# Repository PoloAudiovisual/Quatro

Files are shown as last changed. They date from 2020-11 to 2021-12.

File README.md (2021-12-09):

Front panel, gerbers, BOM and schematics for **[Quatro](https://www.olivellamodular.com/quatro.html), an Eurorack synthesizer module from [Olivella Modular](https://www.olivellamodular.com/)**.

Based on Veils v1 from Mutable Instruments. [Original design](https://github.com/pichenettes/eurorack) by Émilie Gillet. Through-hole remix by Kevin Olivella.

License
=======

[CC BY-SA 3.0][cc-by-sa].

[][cc-by-sa]

[cc-by-sa]: http://creativecommons.org/licenses/by-sa/3.0/
[cc-by-sa-image]: https://licensebuttons.net/l/by-sa/3.0/88x31.png
[cc-by-sa-shield]: https://img.shields.io/badge/License-CC%20BY--SA%203.0-lightgrey.svg

CC BY-SA 3.0 does not confer the right to use intellectual property such as trademarks, brand names, and logos. Olivella Modular, Quatro, Mutable Instruments, and Veils are trademarks of their respective owners and should not be used without permission.

By Kevin Olivella (kev.olivella@gmail.com)

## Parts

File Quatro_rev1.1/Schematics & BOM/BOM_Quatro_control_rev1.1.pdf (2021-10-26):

## BOM Quatro – Control Board – rev 1.1

ID | Name / Value | Designator | Format | QTY
| | Resistors
1 | 510 | R2,R10,R15,R16,R17,R18,R19,R20 | Horizontal | 8
2 | 75k | R3,R6,R9,R13 | Horizontal | 4
3 | 100k | R1,R4,R5,R7,R8,R11,R12,R14 | Horizontal | 8
| | LEDs
4 | 5ARG4HWC 5mm | LED1,LED2,LED3,LED4 | Bipolar LED 5mm | 4
| | Potentiometers
5 | GAIN_1 100kB | P2 | Alpha 9mm – 6.35mm round shaft LONG | 1
6 | GAIN_2 100kB | P4 | Alpha 9mm – 6.35mm round shaft LONG | 1
7 | GAIN_3 100kB | P6 | Alpha 9mm – 6.35mm round shaft LONG | 1
8 | GAIN_4 100kB | P8 | Alpha 9mm – 6.35mm round shaft LONG | 1
9 | CV_1 100kB | P1 | SongHuei 9mm - TALL trimmer | 1
10 | CV_2 100kB | P3 | SongHuei 9mm - TALL trimmer | 1
11 | CV_3 100kB | P5 | SongHuei 9mm - TALL trimmer | 1
12 | CV_4 100kB | P7 | SongHuei 9mm - TALL trimmer | 1
13 | LINEXP_1 100kB | R33 | SongHuei 9mm - TALL trimmer | 1
14 | LINEXP_2 100kB | R34 | SongHuei 9mm - TALL trimmer | 1
15 | LINEXP_3 100kB | R36 | SongHuei 9mm - TALL trimmer | 1
16 | LINEXP_4 100kB | R35 | SongHuei 9mm - TALL trimmer | 1
| | Female headers
17 | VCA_1_2-VCA_3_4 | H1,H2 | HDR-12X1 / 2.54mm | 2
18 | LEDS | H3 | HDR-8X1 / 2.54mm | 1
19 | RAILS | H4 | HDR-5X1 / 2.54mm | 1
| | Jacks
20 | JACKS | J1 to J12 | PJ-3410 | 12
| | Knobs
21 | Rogan RB small – Blue | https://www.thonk.co.uk/shop/rogan-bFor 6.35mm round shaft pots | 4
22 | Hex key – Small | https://www.thonk.co.uk/shop/rogan-bSmall | 1
| | PCB
23 | Control Board | Quatro_control_rev1.1.zip | 58 x 110mm | 1
| | Front panel
23 | Aluminium panel | Quatro.fpd | Anodized, 60.6 x 128.5mm | 1
28 | Panel screws | --- | M3 x 6mm | 4

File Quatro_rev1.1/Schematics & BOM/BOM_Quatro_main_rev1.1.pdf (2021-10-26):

## BOM Quatro - Main Board – rev 1.1

ID | Name / Value | Designator | Format | QTY
| | Resistors
1 | 510 | R1,R4,R23,R26,R36,R39,R49,R52 | Horizontal | 8
2 | 1.2k | R14,R20,R27,R30 | Horizontal | 4
3 | 4.7k | R57,R58,R61,R63 | Horizontal | 4
4 | 5.1k | R8,R9,R11,R16,R18,R19,R29,R31,R32,R44,R45,R53,R54,R55 | Horizontal | 14
5 | 5.6k | R12,R15,R28 | Horizontal | 3
6 | 10k | R41,R42 | Horizontal | 2
7 | 100k | R3,R6,R21,R24,R34,R37,R47,R50 | Horizontal | 8
8 | 1M | R2,R5,R7,R10,R13,R17,R22,R25 | Horizontal | 8
9 | 10M | R56,R59,R60,R62 | Horizontal | 4
| | Diodes
10 | 1N4733 or 1N5231A | D5,D6 | DO-35 | 2
11 | 1N5819 | D1,D2,D3,D4 | DO-41 | 4
| | Ferrite beads
12 | 2743001111 (Mouser) | L1,L2 | AXIAL-L-4.7X3.5 | 2
| | DIP sockets
13 | 14pin | U3,U4,U5,U6,U7 | DIP-14 | 5
14 | 16pin | U1,U2 | DIP-16 | 2
| | Capacitors
15 | 100pF | C1,C4,C5,C6,C7,C10,C11,C12,C15,C16,C17,C20 | CAP-5.08MM | 12
16 | 560pF | C2,C3,C8,C9,C13,C14,C18,C19 | CAP-5.08MM | 8
17 | 100nF | C23,C24,C25,C26,C27,C28,C29,C30,C31,C32,C33,C34,C35,C36 | CAP-5.08MM | 14
18 | 22uF Panasonic | C21,C22 | CAP-D6.3XF2.5 | 2
| | ICs
19 | AS2164 | U1,U2 | DIP-16 | 2
20 | TL074 | U3,U4,U5,U6,U7 | DIP-14 | 5
| | Male headers
21 | VCA_1_2-VCA_3_4 | H1,H2 | HDR-12X1 / 2.54mm | 4
22 | LEDS | H3 | HDR-8X1 / 2.54mm | 1
23 | RAILS | H4 | HDR-5X1 / 2.54mm | 1
24 | POWER | JP1 | 2X5 pin BOX HEADER | 1
| | PCB
25 | Main Board | Quatro_main_rev1.1.zip | 58 x 110mm | 1
| | Hardware
26 | Standoff (Mouser or Thonk) | 710-970110321 (Mouser) | M3 x 11mm (SW5.5) | 2
27 | Standoff screw | --- | M3 x 4mm | 4

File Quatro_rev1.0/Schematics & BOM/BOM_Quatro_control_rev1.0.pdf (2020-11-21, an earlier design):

## BOM Quatro – Control Board – rev. 1.0

ID | Nombre / Valor | Designación | Formato | Cant.
| | Resistencias
1 | 510 | R2,R10,R15,R16,R17,R18,R19,R20 | Horizontal | 8
2 | 75k | R3,R6,R9,R13 | Horizontal | 4
3 | 100k | R1,R4,R5,R7,R8,R11,R12,R14 | Horizontal | 8
| | LEDs
4 | 5ARG4HWC 5mm | LED1,LED2,LED3,LED4 | LED-DIP/5mm | 4
| | Potenciómetros
5 | GAIN_1 100kB | P2 | Alpha 9mm | 1
6 | GAIN_2 100kB | P4 | Alpha 9mm | 1
7 | GAIN_3 100kB | P6 | Alpha 9mm | 1
8 | GAIN_4 100kB | P8 | Alpha 9mm | 1
9 | CV_1 100kB | P1 | SongHuei 9mm trimpot | 1
10 | CV_2 100kB | P3 | SongHuei 9mm trimpot | 1
11 | CV_3 100kB | P5 | SongHuei 9mm trimpot | 1
12 | CV_4 100kB | P7 | SongHuei 9mm trimpot | 1
13 | LINEXP_1 100kB | R33 | SongHuei 9mm trimpot | 1
14 | LINEXP_2 100kB | R34 | SongHuei 9mm trimpot | 1
15 | LINEXP_3 100kB | R36 | SongHuei 9mm trimpot | 1
16 | LINEXP_4 100kB | R35 | SongHuei 9mm trimpot | 1
| | Jacks
20 | JACKS | J1 a J12 | PJ-3410, JAPAN | 12
| | Conectores (hembra)
17 | VCA | P9,P10,P11,P12 | HDR-6X1/2.54mm | 4
18 | RAILS | P13 | HDR-5X1/2.54mm | 1
19 | LEDS | P14 | HDR-8X1/2.54mm | 1

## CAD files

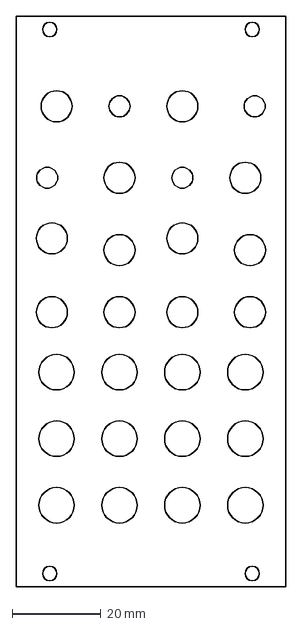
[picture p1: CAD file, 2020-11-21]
Front panel/Quatro_CNC.dxf
60.6 x 128.5 mm

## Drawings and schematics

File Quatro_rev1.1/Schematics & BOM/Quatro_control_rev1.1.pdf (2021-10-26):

# Audio in Audio out

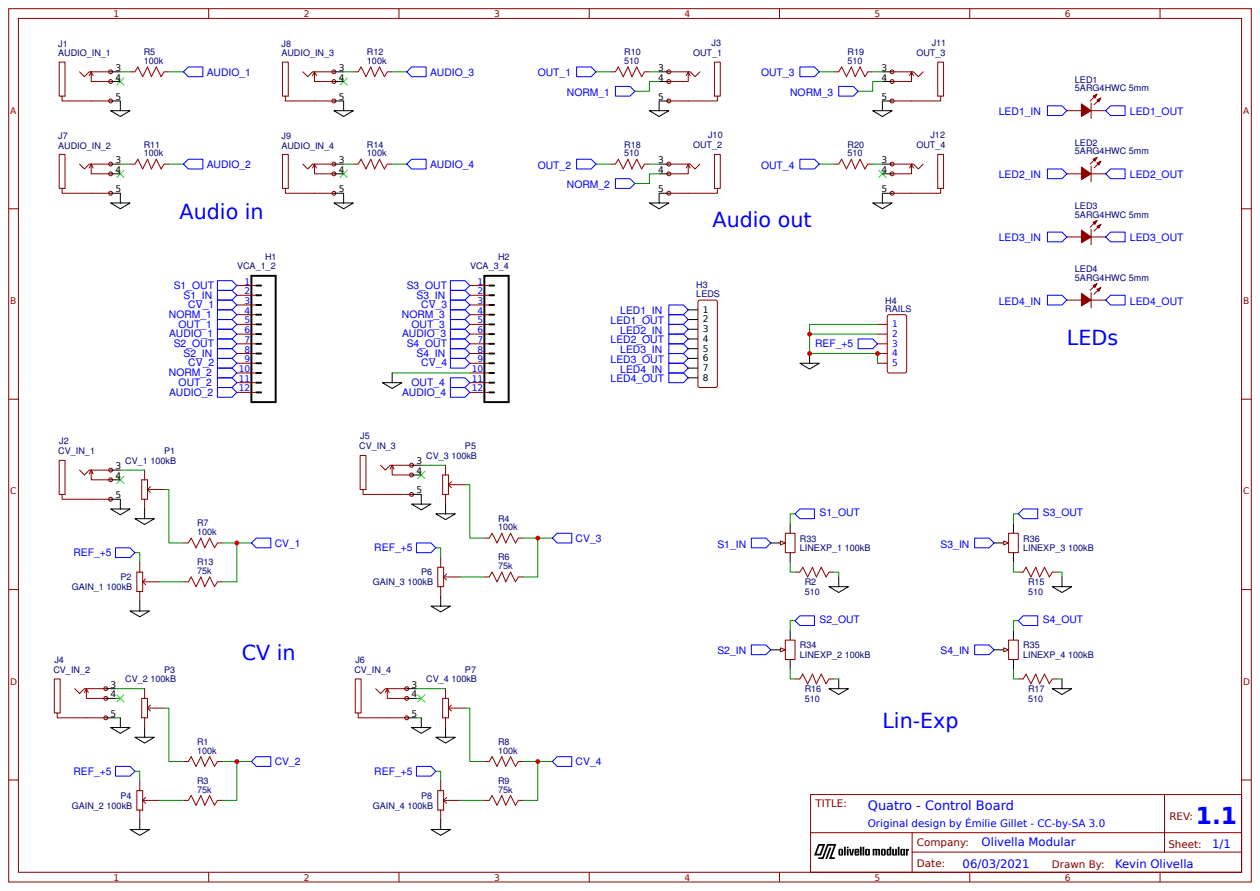
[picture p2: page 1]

Original design by Émilie Gillet - CC-by-SA 3.0

Drawn By: Kevin Olivella

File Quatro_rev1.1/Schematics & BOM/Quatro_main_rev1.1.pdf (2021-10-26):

VCA 1 | VCA 2

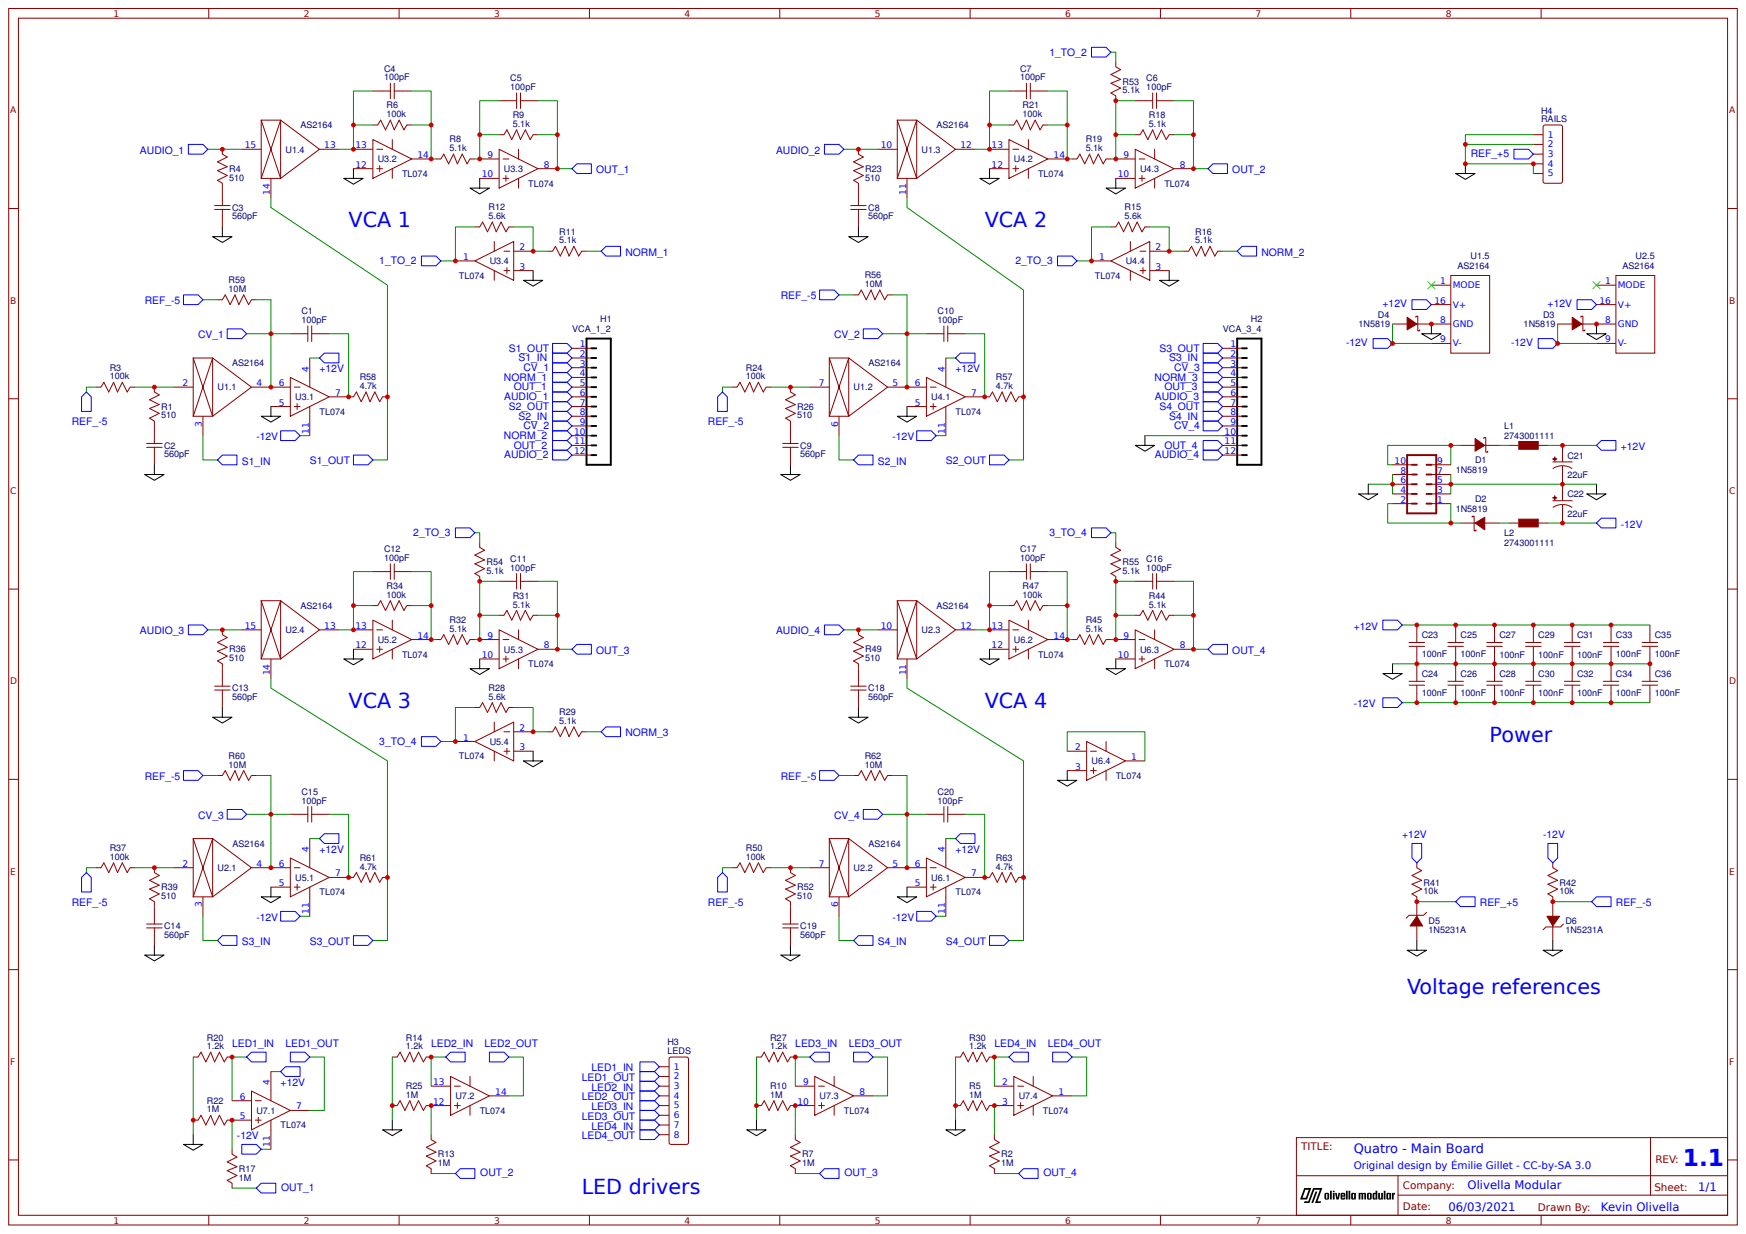
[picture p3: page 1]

Original design by Émilie Gillet - CC-by-SA 3.0

Drawn By: Kevin Olivella

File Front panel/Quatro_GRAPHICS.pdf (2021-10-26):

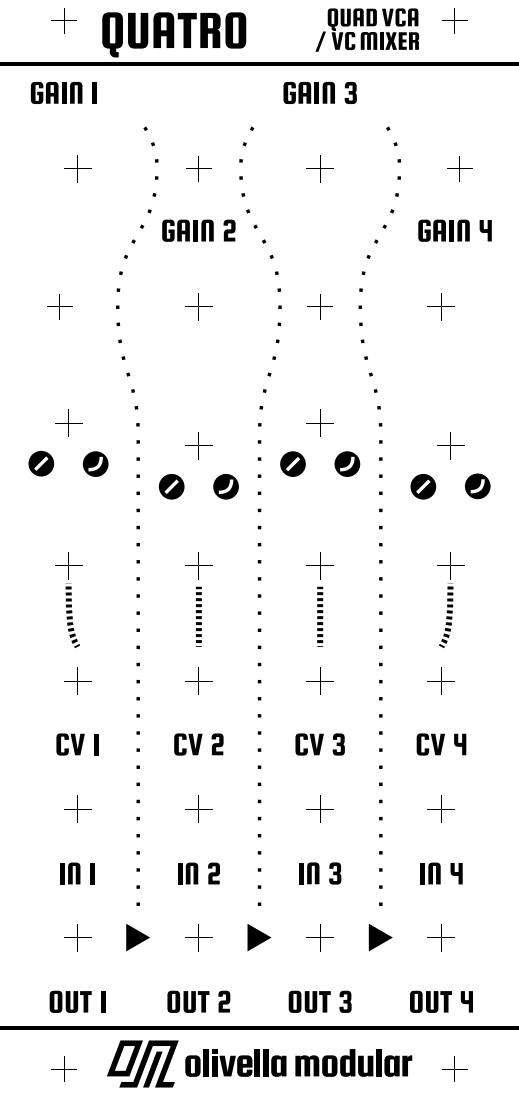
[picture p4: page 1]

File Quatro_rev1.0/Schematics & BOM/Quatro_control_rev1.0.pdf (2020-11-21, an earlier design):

# Audio in Audio out

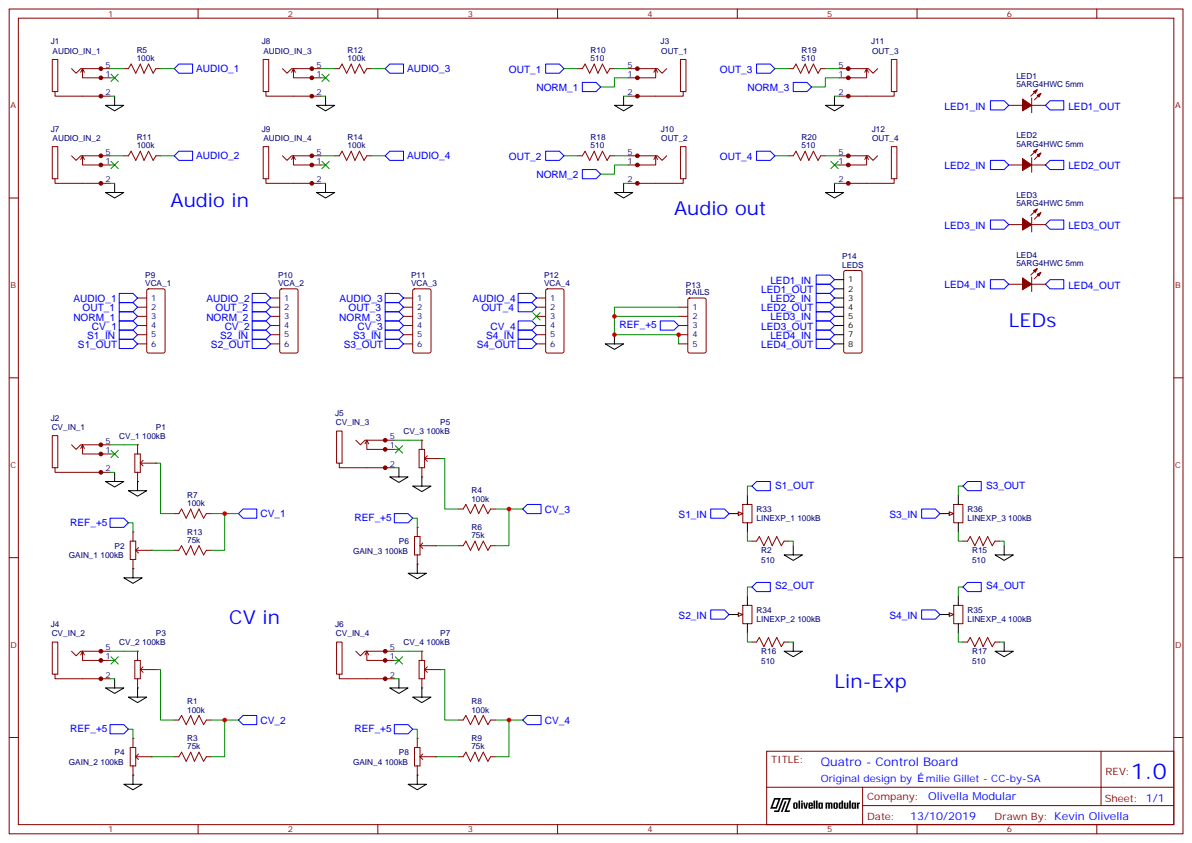
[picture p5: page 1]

Original design by milie Gillet - CC-by-SA

Drawn By: Kevin Olivella

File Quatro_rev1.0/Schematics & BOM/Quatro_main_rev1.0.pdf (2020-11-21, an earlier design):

VCA 1 | VCA 2

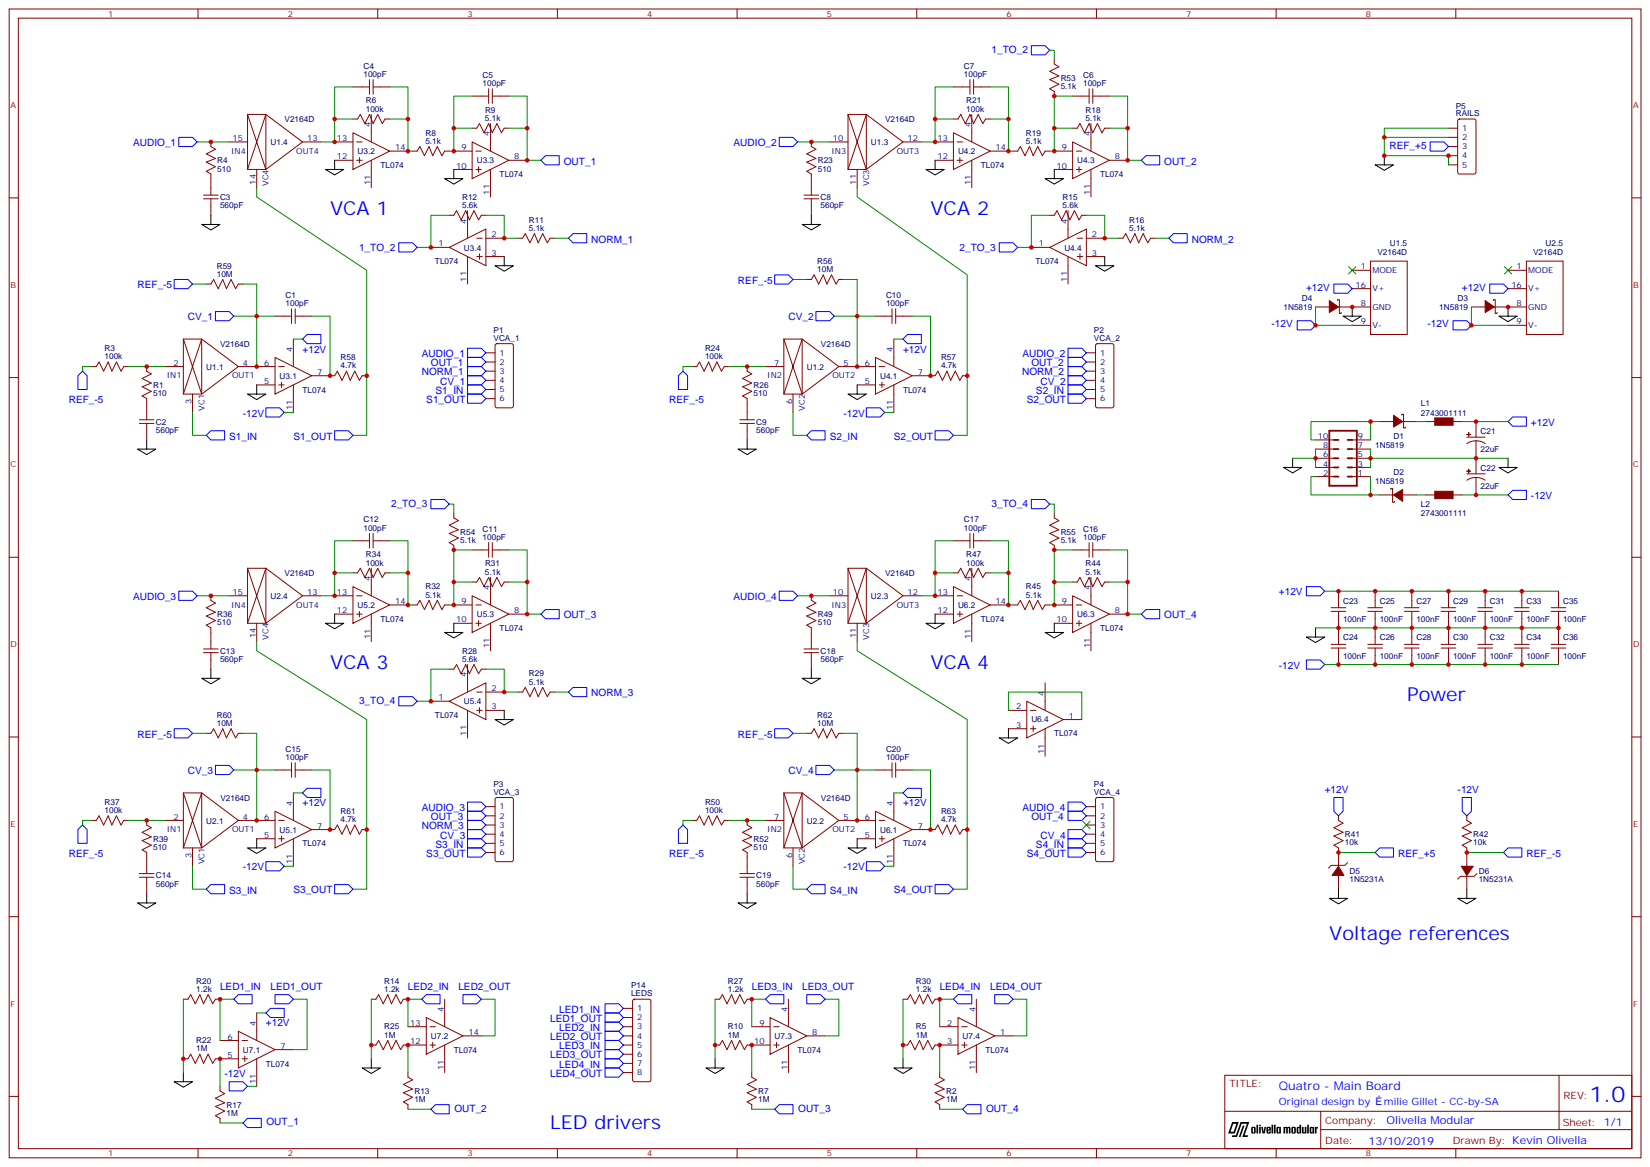
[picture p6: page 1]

Original design by milie Gillet - CC-by-SA

Drawn By: Kevin Olivella

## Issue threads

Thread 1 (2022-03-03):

could you upload the information for users of v1.0 boards?

KeLaiFu, 2022-03-03:
I have a bunch of the older v1 boards, which I built a set of and the module is working great so thanks for that. I wish to send a set of the boards to a friend but the information about the jack modification is no longer available.

Many thanks

*edit* found the same info in the other repository *thumbs*

PoloAudiovisual, 2022-03-03:
Just uploaded rev1.0 and rev1.1 separately, including the jack mod guide for rev1.0.
Front panel files are the same for both versions.

Glad you liked it @KeLaiFu !

Closed 2022-03-03.
